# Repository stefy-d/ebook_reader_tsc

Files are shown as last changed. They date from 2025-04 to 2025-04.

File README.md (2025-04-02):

## **Manea Ștefania-Delia**
### **Grupa 335CC** 
<br><br>

# **Pașii de implementare**  
- Realizarea schematicului
- Plasarea componentelor pe PCB
- Trasarea circuitelor și optimizarea rutării semnalelor
- Încărcarea modelelor 3D pentru fiecare componentă
- Crearea bateriei și a display-ului
- Inserarea PCB-ului, a bateriei și a display-ului în carcasa 3D
<br><br> 

# **Diagramă bloc**
```` mermaid
graph TD;
    USB_C[USB C Connector & ESD Protection] -->|Power & Data| LDO[LDO Voltage Regulator];
    LDO -->|3.3V Power| ESP32[ESP32 C6];
    LDO -->|3.3V Power| SD[SD Card];
    LDO -->|3.3V Power| RTC[RTC Module DS3231SN];
    LDO -->|3.3V Power| Sensor[Environmental Sensor BME688];
    LDO -->|3.3V Power| Display[EPD Power];
    ESP32 -->|SPI| SD;
    ESP32 -->|I2C| RTC;
    ESP32 -->|I2C| Sensor;
    ESP32 -->|SPI| Display;
    ESP32 -->|GPIO| Button[Voltage Supervisor + Reset & Boot / IO Button];
    ESP32 -->|SPI| Flash[External NOR Flash 64MB];
    ESP32 -->|GPIO| ChargeLevel[Battery Charge Level];
    ESP32 -->|GPIO| Selector[Display Type Selector];
    ChargeController[Li-Po Battery Charging Controller] -->|Power| LDO;
    ChargeController -->|Battery Status| ChargeLevel;

`````
<br><br>

# **BOM (Bill Of Materials)**

| Componenta | X | Y | Rotatie | Valoare | Package | Link | 
|---|---|---|---|---|---|---|
| BOOT_BUTTON | 23.90  | 108.41 | 180.00 | BUTTON_CUSYOMV1 | MYBUTTON | https://industry.panasonic.com/global/en/products/control/switch/light-touch/number/evqpuj02k |
| C1 | 154.64 | 6.13 | 90.00 | 100nF | ESP32_WROVER_EAGLE-LTSPICE_C0402 | https://componentsearchengine.com/part-view/CC0402MRX5R5BB106/YAGEO |
| C10 | 67.34  | 107.83 | 270.00 | 100nF | ESP32_WROVER_EAGLE-LTSPICE_C0402 | https://componentsearchengine.com/part-view/CC0402MRX5R5BB106/YAGEO |
| C10_SUPERCAP | 93.09  | 55.34  | 90.00 | CPH3225A | CAPCP3225X100N  | https://www.snapeda.com/parts/CPH3225A/Seiko+Instruments/view-part/?ref=eda |
| C1_BAT | 107.73 | 50.25  | 0.00 | 4.7uF | ESP32_WROVER_EAGLE-LTSPICE_C0402 | https://componentsearchengine.com/part-view/CC0402MRX5R5BB106/YAGEO |
| C1_BAT1 | 109.19 | 37.99  | 0.00 | 4.7uF | ESP32_WROVER_EAGLE-LTSPICE_C0402 | https://componentsearchengine.com/part-view/CC0402MRX5R5BB106/YAGEO |
| C1_BAT2 | 104.58 | 40.47  | 90.00 | 4.7uF | ESP32_WROVER_EAGLE-LTSPICE_C0402 | https://componentsearchengine.com/part-view/CC0402MRX5R5BB106/YAGEO |
| C2 | 153.42 | 6.13 | 90.00 | 100nF | ESP32_WROVER_EAGLE-LTSPICE_C0402 | https://componentsearchengine.com/part-view/CC0402MRX5R5BB106/YAGEO |
| C2_BAT | 120.94 | 51.25  | 90.00 | 4.7uF | ESP32_WROVER_EAGLE-LTSPICE_C0402 | https://componentsearchengine.com/part-view/CC0402MRX5R5BB106/YAGEO |
| C3 | 118.89 | 41.40  | 90.00 | 100uF | RCL_CT3528 | https://eu.mouser.com/ProductDetail/KYOCERA-AVX/F910J107MBAAJ6?qs=PqoDHHvF649LraCA%2FjeGXg%3D%3D |
| C4 | 90.95  | 35.19  | 90.00 | 4.7uF/25V | ESP32_WROVER_EAGLE-LTSPICE_C0402 | https://componentsearchengine.com/part-view/CC0402MRX5R5BB106/YAGEO |
| C4_USB | 149.29 | 50.17  | 90.00 | 100nF | ESP32_WROVER_EAGLE-LTSPICE_C0402 | https://componentsearchengine.com/part-view/CC0402MRX5R5BB106/YAGEO |
| C5 | 52.21  | 107.71 | 270.00 | 1uF | ESP32_WROVER_EAGLE-LTSPICE_C0402 | https://componentsearchengine.com/part-view/CC0402MRX5R5BB106/YAGEO |
| C5_USB | 155.40 | 52.97  | 90.00 | 4.7uF | ESP32_WROVER_EAGLE-LTSPICE_C0402 | https://componentsearchengine.com/part-view/CC0402MRX5R5BB106/YAGEO |
| C6 | 27.30  | 107.83 | 270.00 | 100nF | ESP32_WROVER_EAGLE-LTSPICE_C0402 | https://componentsearchengine.com/part-view/CC0402MRX5R5BB106/YAGEO |
| C7 | 80.29  | 30.73  | 0.00 | 10uF | ESP32_WROVER_EAGLE-LTSPICE_C0402 | https://componentsearchengine.com/part-view/CC0402MRX5R5BB106/YAGEO |
| C8 | 84.28  | 52.43  | 180.00 | 100nF | ESP32_WROVER_EAGLE-LTSPICE_C0402 | https://componentsearchengine.com/part-view/CC0402MRX5R5BB106/YAGEO |
| C9 | 10.66  | 99.03  | 90.00 | 100nF | ESP32_WROVER_EAGLE-LTSPICE_C0402 | https://componentsearchengine.com/part-view/CC0402MRX5R5BB106/YAGEO |
| CHANGE_BUTTON  | 64.00  | 108.48 | 179.30 | BUTTON_CUSYOMV1 | MYBUTTON | https://industry.panasonic.com/global/en/products/control/switch/light-touch/number/evqpuj02k |
| CHG_LED | 111.34 | 50.15  | 90.00 | | ADAFRUIT_CHIP-LED0603 | https://www.snapeda.com/parts/KP-1608SURCK/Kingbright/view-part/?ref=search&t=LED%200603 |
| C_DELAY | 51.93  | 101.29 | 269.50 | 100nF | ESP32_WROVER_EAGLE-LTSPICE_C0402 | https://componentsearchengine.com/part-view/CC0402MRX5R5BB106/YAGEO |
| D1 | 152.58 | 50.47  | 0.00 | USBLC6-2SC6Y | SOT95P280X145-6N | https://www.snapeda.com/parts/USBLC6-2SC6Y/STMicroelectronics/view-part/?ref=eda |
| D10 | 44.62  | 38.77  | 90.00 | PGB1010603MR | DIOC1608X36N | https://www.snapeda.com/parts/PGB1010603MR/Littelfuse/view-part/?ref=eda |
| D11 | 42.60  | 38.67  | 90.00 | PGB1010603MR | DIOC1608X36N | https://www.snapeda.com/parts/PGB1010603MR/Littelfuse/view-part/?ref=eda |
| D12 | 38.38  | 38.87  | 90.00 | PGB1010603MR | DIOC1608X36N | https://www.snapeda.com/parts/PGB1010603MR/Littelfuse/view-part/?ref=eda |
| D2 | 122.09 | 41.08  | 90.00 | ESP32_WROVER_AVX---SD0805S020S1R0_AVX_SD0805S020S1R0_0_0AVX_SD0805S020S1R0_0_0 | ESP32_WROVER_AVX---SD0805S020S1R0_AVX_SD0805S020S1R0_0 | https://eu.mouser.com/ProductDetail/KYOCERA-AVX/SD0805S020S1R0?qs=jCA%252BPfw4LHbpkAoSnwrdjw%3D%3D |
| D3 | 87.16  | 35.47  | 180.00 | MBR0530 | SOD3716X135N | https://www.snapeda.com/parts/MBR0530/Onsemi/view-part/?ref=eda |
| D4 | 87.22  | 31.68  | 0.00 | MBR0530 | SOD3716X135N | https://www.snapeda.com/parts/MBR0530/Onsemi/view-part/?ref=eda |
| D5 | 80.26  | 40.58  | 180.00 | MBR0530 | SOD3716X135N | https://www.snapeda.com/parts/MBR0530/Onsemi/view-part/?ref=eda |
| D6 | 73.98  | 26.87  | 0.00 | PGB1010603MR | DIOC1608X36N | https://www.snapeda.com/parts/PGB1010603MR/Littelfuse/view-part/?ref=eda |
| D7 | 83.64  | 68.93  | 0.00 | ESP32_WROVER_AVX---SD0805S020S1R0_AVX_SD0805S020S1R0_0_0AVX_SD0805S020S1R0_0_0 | ESP32_WROVER_AVX---SD0805S020S1R0_AVX_SD0805S020S1R0_0 | https://eu.mouser.com/ProductDetail/KYOCERA-AVX/SD0805S020S1R0?qs=jCA%252BPfw4LHbpkAoSnwrdjw%3D%3D |
| D8 | 14.96  | 98.57  | 0.00 | PGB1010603MR | DIOC1608X36N | https://www.snapeda.com/parts/PGB1010603MR/Littelfuse/view-part/?ref=eda
| D9 | 33.14  | 47.17  | 270.00 | PGB1010603MR | DIOC1608X36N | https://www.snapeda.com/parts/PGB1010603MR/Littelfuse/view-part/?ref=eda |
| EPD_C1 | 88.71  | 21.47  | 90.00 | 1uF/50V | ESP32_WROVER_EAGLE-LTSPICE_C0402 | https://componentsearchengine.com/part-view/CC0402MRX5R5BB106/YAGEO |
| EPD_C10 | 76.31  | 21.47  | 90.00 | 1uF/50V | ESP32_WROVER_EAGLE-LTSPICE_C0402 | https://componentsearchengine.com/part-view/CC0402MRX5R5BB106/YAGEO |
| EPD_C11 | 72.05  | 18.89  | 90.00 | 1uF/50V | ESP32_WROVER_EAGLE-LTSPICE_C0402 | https://componentsearchengine.com/part-view/CC0402MRX5R5BB106/YAGEO |
| EPD_C12 | 70.61  | 18.79  | 90.00 | 1uF/50V | ESP32_WROVER_EAGLE-LTSPICE_C0402 | https://componentsearchengine.com/part-view/CC0402MRX5R5BB106/YAGEO |
| EPD_C2 | 87.32  | 21.47  | 90.00 | 1uF/50V | ESP32_WROVER_EAGLE-LTSPICE_C0402 | https://componentsearchengine.com/part-view/CC0402MRX5R5BB106/YAGEO |
| EPD_C5 | 85.68  | 21.45  | 90.00 | 1uF/50V | ESP32_WROVER_EAGLE-LTSPICE_C0402 | https://componentsearchengine.com/part-view/CC0402MRX5R5BB106/YAGEO |
| EPD_C6 | 81.95  | 21.49  | 270.00 | 1uF/50V | ESP32_WROVER_EAGLE-LTSPICE_C0402 | https://componentsearchengine.com/part-view/CC0402MRX5R5BB106/YAGEO |
| EPD_C7 | 80.55  | 21.50  | 90.00 | 1uF/50V | ESP32_WROVER_EAGLE-LTSPICE_C0402 | https://componentsearchengine.com/part-view/CC0402MRX5R5BB106/YAGEO |
| EPD_C8 | 79.15  | 21.51  | 90.00 | 1uF/50V | ESP32_WROVER_EAGLE-LTSPICE_C0402 | https://componentsearchengine.com/part-view/CC0402MRX5R5BB106/YAGEO |
| EPD_C9 | 77.75  | 21.52  | 90.00 | 1uF/50V | ESP32_WROVER_EAGLE-LTSPICE_C0402 | https://componentsearchengine.com/part-view/CC0402MRX5R5BB106/YAGEO |
| IC1 | 48.65  | 101.27 | 0.00 | BD5229G-TR | SOT95P280X125-5N | https://componentsearchengine.com/part-view/BD5229G-TR/ROHM%20Semiconductor |
| IC4 | 113.73 | 40.29  | 0.00 | XC6220A331MR-G | SOT95P280X120-5N | https://componentsearchengine.com/part-view/XC6220A331MR-G/Torex |
| J1 | 83.10  | 14.17  | 0.00 | FH34SRJ-24S-0.5SH_99_ | FH34SRJ24S05SH99 | https://componentsearchengine.com/part-view/FH34SRJ-24S-0.5SH(99)/Hirose |
| J2 | 165.53 | 54.30  | 90.00 | SAMACSYS_PARTS_USB4110-GF-A | SAMACSYS_PARTS_USB4110GFA | https://componentsearchengine.com/part-view/USB4110-GF-A/GCT%20(GLOBAL%20CONNECTOR%20TECHNOLOGY) |
| J3 | 166.35 | 19.30  | 90.00 | QWIIC_RIGHT_ANGLE | JST04_1MM_RA | https://eu.mouser.com/ProductDetail/Adafruit/4208?qs=PzGy0jfpSMtbScLbr0L5dw%3D%3D |
| J4 | 9.09 | 88.88  | 270.00 | 112A-TAAR-R03_ATTEND | 112ATAARR03ATTEND | https://store.comet.srl.ro/Catalogue/Product/43497/ |
| L1 | 80.35  | 35.77  | 270.00 | 68uH | IND_4828-WE-TPC_WRE | https://eu.mouser.com/ProductDetail/Wurth-Elektronik/744043680?qs=PGXP4M47uW6VkZq%252BkzjrHA%3D%3D |
| MCP73831  | 116.79 | 49.69  | 90.00 | ESP32_WROVER_SPARKFUN-IC-POWER_MCP73831 | ESP32_WROVER_SPARKFUN-IC-POWER_SOT23-5 | https://eu.mouser.com/ProductDetail/Microchip-Technology/MCP73831T-2ACI-OT?qs=yUQqVecv4qvbBQBGbHx0Mw%3D%3D |
| PFMF.050.1| 151.74 | 43.60  | 0.00 | ESP32C6_VARISTORCN1812 | ESP32C6_VARISTOR_CT/CN1812 | https://www.mouser.co.uk/ProductDetail/EPCOS-TDK/B72520T0350K062?qs=dEfas%2FXlABIszF52uu7vrg%3D%3D |
| Q1 | 123.56 | 47.31  | 0.00 | 20V/4.2A/52mΩ/1.4W | ESP32_WROVER_SPARKFUN-DISCRETESEMI_SOT23-3 | https://componentsearchengine.com/part-view/DMG2305UX-7/Diodes%20Incorporated |
| Q2 | 76.03  | 31.36  | 270.00 | 20V/4.2A/52mΩ/1.4W | ESP32_WROVER_SPARKFUN-DISCRETESEMI_SOT23-3 | https://componentsearchengine.com/part-view/DMG2305UX-7/Diodes%20Incorporated |
| Q3 | 67.19  | 15.28  | 90.00 | SI1308EDL-T1-GE3 | SOT65P210X110-3N | https://www.snapeda.com/parts/SI1308EDL-T1-GE3/Vishay+Siliconix/view-part/?ref=eda |
| R1 | 19.35  | 42.13  | 270.00 | 10K | ESP32_WROVER_EAGLE-LTSPICE_R0402 | https://componentsearchengine.com/part-view/R0402%201%25%20100%20K%20(RC0402FR-07100KL)/YAGEO |
| R10 | 12.23  | 99.03  | 90.00 | 10K | ESP32_WROVER_EAGLE-LTSPICE_R0402 | https://componentsearchengine.com/part-view/R0402%201%25%20100%20K%20(RC0402FR-07100KL)/YAGEO |
| R1_BAT | 111.55 | 48.75  | 0.00 | 200 | ESP32_WROVER_EAGLE-LTSPICE_R0402 |
| R1_PINH | 156.12 | 6.27 | 90.00 | 10K | ESP32_WROVER_EAGLE-LTSPICE_R0402 | https://componentsearchengine.com/part-view/R0402%201%25%20100%20K%20(RC0402FR-07100KL)/YAGEO |
| R1_PINH1  | 83.56  | 66.94  | 0.00 | 10K | ESP32_WROVER_EAGLE-LTSPICE_R0402 | https://componentsearchengine.com/part-view/R0402%201%25%20100%20K%20(RC0402FR-07100KL)/YAGEO |
| R1_PWRUSB | 106.25 | 40.54  | 90.00 | 100k | ESP32_WROVER_EAGLE-LTSPICE_R0402 | https://componentsearchengine.com/part-view/R0402%201%25%20100%20K%20(RC0402FR-07100KL)/YAGEO |
| R2 | 65.73  | 11.51  | 0.00 | 2.2 | ESP32_WROVER_EAGLE-LTSPICE_R0402 | https://componentsearchengine.com/part-view/R0402%201%25%20100%20K%20(RC0402FR-07100KL)/YAGEO |
| R2-PINH | 157.48 | 6.27 | 90.00 | 10K | ESP32_WROVER_EAGLE-LTSPICE_R0402 | https://componentsearchengine.com/part-view/R0402%201%25%20100%20K%20(RC0402FR-07100KL)/YAGEO |
| R2-USB | 152.58 | 46.33  | 0.00 | 5k1 | ESP32_WROVER_EAGLE-LTSPICE_R0402 | https://componentsearchengine.com/part-view/R0402%201%25%20100%20K%20(RC0402FR-07100KL)/YAGEO |
| R2-USB1 | 152.56 | 47.77  | 0.00 | 5k1 | ESP32_WROVER_EAGLE-LTSPICE_R0402 | https://componentsearchengine.com/part-view/R0402%201%25%20100%20K%20(RC0402FR-07100KL)/YAGEO |
| R2_BAT | 115.66 | 46.05  | 90.00 | 2K | ESP32_WROVER_EAGLE-LTSPICE_R0402 | https://componentsearchengine.com/part-view/R0402%201%25%20100%20K%20(RC0402FR-07100KL)/YAGEO |
| R2_PINH1  | 89.11  | 63.79  | 90.00 | 10K | ESP32_WROVER_EAGLE-LTSPICE_R0402 | https://componentsearchengine.com/part-view/R0402%201%25%20100%20K%20(RC0402FR-07100KL)/YAGEO |
| R3 | 68.71  | 9.53 | 90.00 | 0.47 | ESP32_WROVER_EAGLE-LTSPICE_R0402 | https://componentsearchengine.com/part-view/R0402%201%25%20100%20K%20(RC0402FR-07100KL)/YAGEO |
| R4 | 70.49  | 13.91  | 0.00 | 10K | ESP32_WROVER_EAGLE-LTSPICE_R0402 | https://componentsearchengine.com/part-view/R0402%201%25%20100%20K%20(RC0402FR-07100KL)/YAGEO |
| R5 | 31.21  | 47.21  | 270.00 | 10K | ESP32_WROVER_EAGLE-LTSPICE_R0402 | https://componentsearchengine.com/part-view/R0402%201%25%20100%20K%20(RC0402FR-07100KL)/YAGEO |
| R6 | 44.53  | 33.41  | 92.20 | 10K | ESP32_WROVER_EAGLE-LTSPICE_R0402 | https://componentsearchengine.com/part-view/R0402%201%25%20100%20K%20(RC0402FR-07100KL)/YAGEO |
| R7 | 42.45  | 33.61  | 270.00 | 10K | ESP32_WROVER_EAGLE-LTSPICE_R0402 | https://componentsearchengine.com/part-view/R0402%201%25%20100%20K%20(RC0402FR-07100KL)/YAGEO |
| R8 | 38.57  | 33.41  | 90.00 | 10K | ESP32_WROVER_EAGLE-LTSPICE_R0402 | https://componentsearchengine.com/part-view/R0402%201%25%20100%20K%20(RC0402FR-07100KL)/YAGEO |
| R9 | 70.89  | 31.31  | 90.00 | 10K | ESP32_WROVER_EAGLE-LTSPICE_R0402 | https://componentsearchengine.com/part-view/R0402%201%25%20100%20K%20(RC0402FR-07100KL)/YAGEO |
| RESET_BUTTON | 48.90 | 108.49 | 180.40 | BUTTON_CUSYOMV1  | MYBUTTON | https://industry.panasonic.com/global/en/products/control/switch/light-touch/number/evqpuj02k |
| R_BOOT | 20.27  | 107.67  | 270.00 | 10K | ESP32_WROVER_EAGLE-LTSPICE_R0402 | https://componentsearchengine.com/part-view/R0402%201%25%20100%20K%20(RC0402FR-07100KL)/YAGEO |
| R_CAPACITOR | 88.95 | 55.04  | 270.00 | 15 | ESP32_WROVER_EAGLE-LTSPICE_R0402 | https://componentsearchengine.com/part-view/R0402%201%25%20100%20K%20(RC0402FR-07100KL)/YAGEO |
| R_CHANGE  | 60.62  | 107.78  | 90.00 | 10K | ESP32_WROVER_EAGLE-LTSPICE_R0402 | https://componentsearchengine.com/part-view/R0402%201%25%20100%20K%20(RC0402FR-07100KL)/YAGEO |
| R_CL1 | 72.96  | 31.23  | 90.00 | 10K | ESP32_WROVER_EAGLE-LTSPICE_R0402 | https://componentsearchengine.com/part-view/R0402%201%25%20100%20K%20(RC0402FR-07100KL)/YAGEO |
| R_RESET | 45.19  | 107.69  | 269.80 | 10K | ESP32_WROVER_EAGLE-LTSPICE_R0402 | https://componentsearchengine.com/part-view/R0402%201%25%20100%20K%20(RC0402FR-07100KL)/YAGEO |
| SENSOR2 | 154.46 | 10.42  | 90.00 | ESP32_WROVER_BME680_BME680 | ESP32_WROVER_BME680_PSON80P300X300X100-8N | https://www.snapeda.com/parts/BME680/Bosch/view-part/?welcome=home |
| SJ1 | 65.86  | 9.29 | 0.00 | | SJ | https://grabcad.com/library/solder-jumpers-1 |
| TP1 | 10.51  | 67.29  | 0.00 | TPTP20R | TP20R | CUSTOM
| TP10 | 104.28 | 15.51  | 0.00 | TPTP20R | TP20R | CUSTOM
| TP11 | 100.19 | 19.39  | 0.00 | TPTP20R | TP20R | CUSTOM
| TP12 | 99.83  | 15.81  | 0.00 | TPTP20R | TP20R | CUSTOM
| TP13 | 94.86  | 15.83  | 0.00 | TPTP20R | TP20R | CUSTOM
| TP14 | 135.63 | 50.31  | 0.00 | TPTP20R | TP20R | CUSTOM
| TP15 | 78.68  | 70.51  | 0.00 | TPTP20R | TP20R | CUSTOM
| TP16 | 9.43 | 41.31  | 0.00 | TPTP20R | TP20R | CUSTOM
| TP17 | 95.62  | 19.47  | 0.00 | TPTP20R | TP20R | CUSTOM
| TP2 | 14.23  | 67.49  | 0.00 | TPTP20R | TP20R | CUSTOM
| TP3 | 131.25 | 50.56  | 0.00 | TPTP20R | TP20R | CUSTOM
| TP4 | 131.37 | 54.49  | 0.00 | TPTP20R | TP20R | CUSTOM
| TP5 | 135.89 | 54.39  | 0.00 | TPTP20R | TP20R | CUSTOM
| TP6 | 16.11  | 77.59  | 0.00 | TPTP20R | TP20R | CUSTOM
| TP7 | 11.03  | 77.59  | 0.00 | TPTP20R | TP20R | CUSTOM
| TP8 | 5.95 | 77.59  | 0.00 | TPTP20R | TP20R | CUSTOM
| TP9 | 104.67 | 19.19  | 0.00 | TPTP20R | TP20R | CUSTOM
| U1 | 36.89  | 54.16  | 0.00 | W25Q512JVEIQ | SON127P600X800X80-9N | https://www.snapeda.com/parts/W25Q512JVEIQ/Winbond+Electronics/view-part/?ref=eda |
| U2 | 16.20  | 54.00  | 90.00 | ESP32-C6-WROOM-1-N8 | XCVR_ESP32-C6-WROOM-1-N8 | https://www.snapeda.com/parts/ESP32-C6-WROOM-1-N8/Espressif+Systems/view-part/?ref=eda |
| U3 | 79.90  | 59.90  | 270.00 | DS3231SN# | SOIC127P1032X265-16N | https://www.snapeda.com/parts/DS3231SN%23/Analog+Devices/view-part/?ref=eda |
| U4 | 126.58 | 50.72  | 0.00 | MAX17048G+T10 | SON50P200X200X80-9N | https://www.snapeda.com/parts/MAX17048G+T10/Analog+Devices/view-part/?ref=eda |

<br><br>

# **Pini ESP32-C6**

ESP32-C6 are mai mulți pini utilizați pentru conectarea componentelor din schema bloc. Mai jos este o descriere detaliată a pinilor folosiți și justificarea utilizării lor:

### **1. SD Card (SPI)**
   - **Pini utilizați**:
     - **IO6 (CLK/SCK)** - Semnal de ceas SPI
     - **IO7 (MOSI)** - Linie de date pentru transmitere
     - **IO2 (MISO)** - Linie de date pentru recepție
     - **IO10 (CS)** - Chip Select pentru activarea cardului SD
   - **Motiv**: Protocolul SPI este ideal pentru cardurile SD, deoarece permite viteze mari de transfer cu un număr redus de pini.

### **2. RTC Module DS3231SN (I2C)**
   - **Pini utilizați**:
     - **IO8 (SCL)** - Linie de ceas I2C
     - **IO9 (SDA)** - Linie de date I2C
   - **Motiv**: DS3231SN folosește protocolul I2C pentru comunicație, ceea ce permite partajarea magistralei cu alți senzori.

### **3. Environmental Sensor BME688 (I2C)**
   - **Pini utilizați**:
     - **IO8 (SCL)** - Linie de ceas I2C (partajat cu RTC)
     - **IO9 (SDA)** - Linie de date I2C (partajat cu RTC)
   - **Motiv**: Folosind I2C, senzorul poate comunica eficient cu ESP32 fără a ocupa pini suplimentari.

### **4. EPD Power (SPI)**
   - **Pini utilizați**:
     - **IO6 (CLK/SCK)** - Semnal de ceas SPI
     - **IO7 (MOSI)** - Linie de date pentru transmitere
     - **IO2 (MISO)** - Linie de date pentru recepție
     - **IO5 (CS)** - Chip Select pentru activarea display-ului
   - **Motiv**: Ecranele E-Paper folosesc adesea SPI datorită vitezei mari de transmitere și latenței reduse.

### **5. Voltage Supervisor + Reset & Boot / IO Button (GPIO)**
   - **Pini utilizați**:
     - **IO0** - Buton BOOT
     - **IO3** - Buton Reset
   - **Motiv**: ESP32 folosește aceste pini pentru a intra în mod de programare și resetare rapidă.

### **6. External NOR Flash 64MB (SPI)**
   - **Pini utilizați**:
     - **IO6 (CLK/SCK)** - Semnal de ceas SPI
     - **IO7 (MOSI)** - Linie de date pentru transmitere
     - **IO2 (MISO)** - Linie de date pentru recepție
     - **IO4 (CS)** - Chip Select pentru activarea memoriei Flash
   - **Motiv**: ESP32 poate extinde memoria utilizând SPI pentru a accesa rapid datele stocate.

### **7. Battery Charge Level (GPIO)**
   - **Pini utilizați**:
     - **IO12 (ADC1_CH3)** - Intrare analogică pentru măsurarea tensiunii bateriei
   - **Motiv**: ESP32 dispune de convertoare ADC care permit măsurarea nivelului de încărcare al bateriei.

### **8. Display Type Selector (GPIO)**
   - **Pini utilizați**:
     - **IO14** - Selector de tip ecran (ex. alb-negru vs. color)
   - **Motiv**: Un pin GPIO poate fi folosit pentru a configura sau selecta diferite moduri de operare ale ecranului.

<br><br>

# **Descriere hardware**  

## **1. Microcontrolerul principal – ESP32-C6**  

ESP32-C6 gestionează toate componentele conectate prin diverse protocoale de comunicație, asigurând interfațarea eficientă cu acestea.  

---

## **2. Module și senzori conectați la ESP32-C6: ca mai sus**  

### **2.1. Stocare – Card SD**  
- **Interfață de comunicare**: SPI   

---

### **2.2. Modul RTC DS3231SN**  
- **Interfață de comunicare**: I2C   

---

### **2.3. Senzor BME688** 
- **Interfață de comunicare**: I2C  

---

### **2.4. Ecran E-Paper (SPI)**  
- **Interfață de comunicare**: SPI 

---

### **2.5. Memorie externă NOR Flash 64MB**  
- **Interfață de comunicare**: SPI   

---

### **2.6. Butoane pentru control**   
- **Interfață de comunicare**: GPIO    

---

### **2.7. Monitorizare baterie**  
- **Interfață de comunicare**: GPIO / ADC  

---

### **2.8. Selector de tip ecran**   
- **Interfață de comunicare**: GPIO  

---

### **3. Alimentare și managementul energiei**  

ESP32-C6 și toate componentele funcționează la **3.3V**, alimentarea fiind gestionată de:  

1. **Regulator de tensiune LDO**   

2. **Controler de încărcare baterie Li-Po**  

---

### **4. Rezumat**  

| **Componentă** | **Interfață** | **Pini ESP32-C6** |
|---|---|---|
| **Card SD** | SPI | IO6, IO7, IO2, IO10 |
| **RTC DS3231SN** | I2C | IO8, IO9 |
| **Senzor BME688** | I2C | IO8, IO9 |
| **Display E-Paper** | SPI | IO6, IO7, IO2, IO5 |
| **Memorie NOR Flash 64MB** | SPI | IO6, IO7, IO2, IO4 |
| **Butoane de control** | GPIO | IO0, IO3 |
| **Monitorizare baterie** | ADC/GPIO | IO12 |
| **Selector de tip ecran** | GPIO | IO14 |

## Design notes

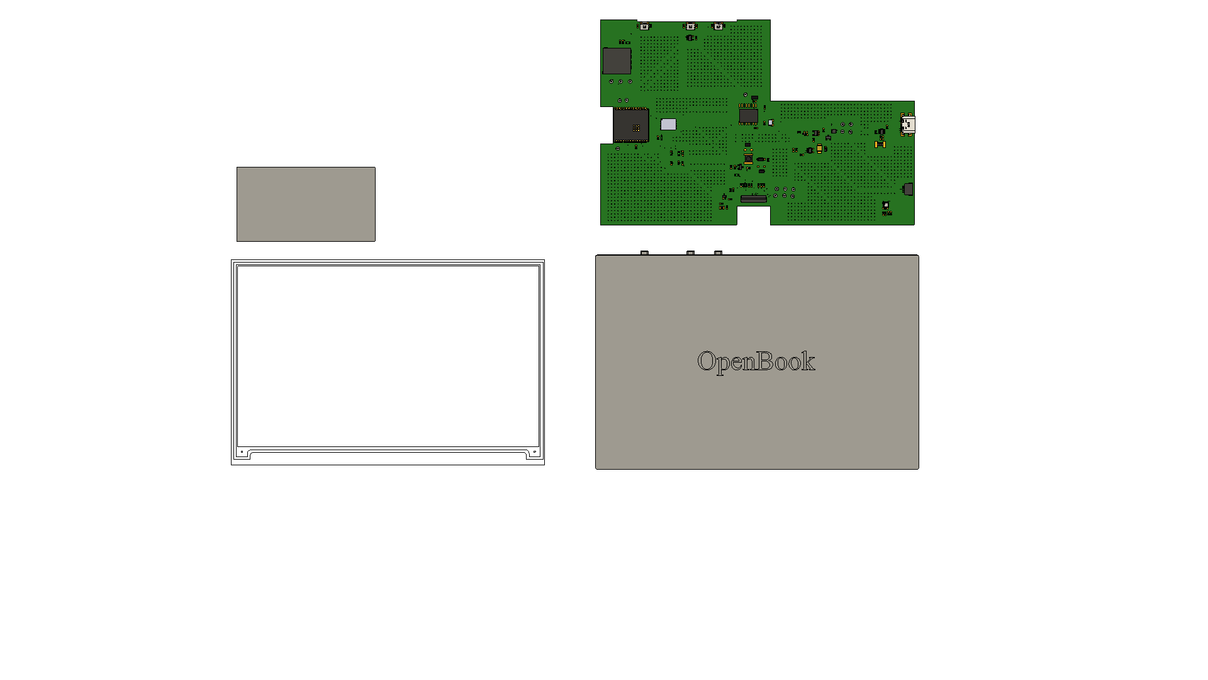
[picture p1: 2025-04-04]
Images/exploded.png

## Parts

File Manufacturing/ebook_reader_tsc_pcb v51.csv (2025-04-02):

Qty | Value | Device | Package | Parts | Description | ARROW_PART_NUMBER | ARROW_PRICE-STOCK | AVAILABILITY | CENTROID_NOT_SPECIFIED | CHECK_PRICES | COPYRIGHT | DATASHEET | DESCRIPTION | DIGIKEY_DESCRIPTION | DIGIKEY_PART_NUMBER | HEIGHT | LEAD_FREE | MANUFACTURER_NAME | MANUFACTURER_PART_NUMBER | MF | MFR_NAME | MOUSER_PART_NUMBER | MOUSER_PRICE-STOCK | MOUSER_TESTING_PART_NUMBER | MOUSER_TESTING_PRICE-STOCK | MP | MPN | PACKAGE | POPULARITY | PREFIX | PRICE | PROD_ID | PURCHASE-URL | ROHS | SNAPEDA_LINK | SPICEMODEL | SPICEPREFIX | TEMPERATURE_RANGE_HIGH | TEMPERATURE_RANGE_LOW | TP_SIGNAL_NAME | VALUE
1 |  | ADAFRUIT_LEDCHIP-LED0603 | ADAFRUIT_CHIP-LED0603 | CHG_LED | LED
1 |  | SJ | SJ | SJ1 | SMD solder JUMPER |  |  |  |  |  |  |  |  |  |  |  |  |  |  |  |  |  |  |  |  |  |  |  | 3
1 | 0.47 | ESP32_WROVER_EAGLE-LTSPICE_RR0402 | ESP32_WROVER_EAGLE-LTSPICE_R0402 | R3 | RESISTOR, European symbol |  |  |  |  |  |  |  |  |  |  |  |  |  |  |  |  |  |  |  |  |  |  |  |  |  |  |  |  |  |  | NONE | R
1 | 100k | ESP32_WROVER_EAGLE-LTSPICE_RR0402 | ESP32_WROVER_EAGLE-LTSPICE_R0402 | R1_PWRUSB | RESISTOR, European symbol |  |  |  |  |  |  |  |  |  |  |  |  |  |  |  |  |  |  |  |  |  |  |  |  |  |  |  |  |  |  | NONE | R
8 | 100nF | ESP32_WROVER_EAGLE-LTSPICE_CC0402 | ESP32_WROVER_EAGLE-LTSPICE_C0402 | C1, C2, C4_USB, C6, C8, C9, C10, C_DELAY | CAPACITOR, European symbol |  |  |  |  |  |  |  |  |  |  |  |  |  |  |  |  |  |  |  |  |  |  |  |  |  |  |  |  |  |  | NONE | C
1 | 100uF | RCL_CPOL-EUCT3528 | RCL_CT3528 | C3 | POLARIZED CAPACITOR, European symbol |  |  |  |  |  |  |  |  |  |  |  |  |  |  |  |  |  |  |  |  |  |  |  | 0 |  |  |  |  |  |  |  | C
16 | 10K | ESP32_WROVER_EAGLE-LTSPICE_RR0402 | ESP32_WROVER_EAGLE-LTSPICE_R0402 | R1, R1_PINH, R1_PINH1, R2-PINH, R2_PINH1, R4, R5, R6, R7, R8, R9, R10, R_BOOT, R_CHANGE, R_CL1, R_RESET | RESISTOR, European symbol |  |  |  |  |  |  |  |  |  |  |  |  |  |  |  |  |  |  |  |  |  |  |  |  |  |  |  |  |  |  | NONE | R
1 | 10uF | ESP32_WROVER_EAGLE-LTSPICE_CC0402 | ESP32_WROVER_EAGLE-LTSPICE_C0402 | C7 | CAPACITOR, European symbol |  |  |  |  |  |  |  |  |  |  |  |  |  |  |  |  |  |  |  |  |  |  |  |  |  |  |  |  |  |  | NONE | C
1 | 112A-TAAR-R03_ATTEND | 112A-TAAR-R03_ATTEND | 112ATAARR03ATTEND | J4 | Micro SD Card Socket, Push-Push Type, Top Mount, SMT, H=1.83mm, 10u |  |  |  |  |  |  |  | Micro SD Card Socket | Push-Push Type | Top Mount | SMT | H=1.83mm | 10u |  |  | 1.9mm |  | ATTEND | 112A-TAAR-R03 ATTEND
1 | 15 | ESP32_WROVER_EAGLE-LTSPICE_RR0402 | ESP32_WROVER_EAGLE-LTSPICE_R0402 | R_CAPACITOR | RESISTOR, European symbol |  |  |  |  |  |  |  |  |  |  |  |  |  |  |  |  |  |  |  |  |  |  |  |  |  |  |  |  |  |  | NONE | R
1 | 1uF | ESP32_WROVER_EAGLE-LTSPICE_CC0402 | ESP32_WROVER_EAGLE-LTSPICE_C0402 | C5 | CAPACITOR, European symbol |  |  |  |  |  |  |  |  |  |  |  |  |  |  |  |  |  |  |  |  |  |  |  |  |  |  |  |  |  |  | NONE | C
10 | 1uF/50V | ESP32_WROVER_EAGLE-LTSPICE_CC0402 | ESP32_WROVER_EAGLE-LTSPICE_C0402 | EPD_C1, EPD_C2, EPD_C5, EPD_C6, EPD_C7, EPD_C8, EPD_C9, EPD_C10, EPD_C11, EPD_C12 | CAPACITOR, European symbol |  |  |  |  |  |  |  |  |  |  |  |  |  |  |  |  |  |  |  |  |  |  |  |  |  |  |  |  |  |  | NONE | C
1 | 2.2 | ESP32_WROVER_EAGLE-LTSPICE_RR0402 | ESP32_WROVER_EAGLE-LTSPICE_R0402 | R2 | RESISTOR, European symbol |  |  |  |  |  |  |  |  |  |  |  |  |  |  |  |  |  |  |  |  |  |  |  |  |  |  |  |  |  |  | NONE | R
1 | 200 | ESP32_WROVER_EAGLE-LTSPICE_RR0402 | ESP32_WROVER_EAGLE-LTSPICE_R0402 | R1_BAT | RESISTOR, European symbol |  |  |  |  |  |  |  |  |  |  |  |  |  |  |  |  |  |  |  |  |  |  |  |  |  |  |  |  |  |  | NONE | R
2 | 20V/4.2A/52m?/1.4W | ESP32_WROVER_SPARKFUN-DISCRETESEMI_MOSFET_PCH-DMG2305UX-7 | ESP32_WROVER_SPARKFUN-DISCRETESEMI_SOT23-3 | Q1, Q2 | P-channel MOSFETs |  |  |  |  |  |  |  |  |  |  |  |  |  |  |  |  |  |  |  |  |  |  |  |  |  |  | TRAN-14388 |  |  |  |  |  |  |  |  | 20V/4.2A/52m?/1.4W
1 | 2K | ESP32_WROVER_EAGLE-LTSPICE_RR0402 | ESP32_WROVER_EAGLE-LTSPICE_R0402 | R2_BAT | RESISTOR, European symbol |  |  |  |  |  |  |  |  |  |  |  |  |  |  |  |  |  |  |  |  |  |  |  |  |  |  |  |  |  |  | NONE | R
5 | 4.7uF | ESP32_WROVER_EAGLE-LTSPICE_CC0402 | ESP32_WROVER_EAGLE-LTSPICE_C0402 | C1_BAT, C1_BAT1, C1_BAT2, C2_BAT, C5_USB | CAPACITOR, European symbol |  |  |  |  |  |  |  |  |  |  |  |  |  |  |  |  |  |  |  |  |  |  |  |  |  |  |  |  |  |  | NONE | C
1 | 4.7uF/25V | ESP32_WROVER_EAGLE-LTSPICE_CC0402 | ESP32_WROVER_EAGLE-LTSPICE_C0402 | C4 | CAPACITOR, European symbol |  |  |  |  |  |  |  |  |  |  |  |  |  |  |  |  |  |  |  |  |  |  |  |  |  |  |  |  |  |  | NONE | C
2 | 5k1 | ESP32_WROVER_EAGLE-LTSPICE_RR0402 | ESP32_WROVER_EAGLE-LTSPICE_R0402 | R2-USB, R2-USB1 | RESISTOR, European symbol |  |  |  |  |  |  |  |  |  |  |  |  |  |  |  |  |  |  |  |  |  |  |  |  |  |  |  |  |  |  | NONE | R
1 | 68uH | 744043680IND_4828-WE-TPC_WRE | IND_4828-WE-TPC_WRE | L1 |  |  |  |  |  |  | Copyright (C) 2024 Ultra Librarian. All rights reserved. |  |  |  |  |  |  |  | 744043680 |  | Wurth Electronics
1 | BD5229G-TR | BD5229G-TR | SOT95P280X125-5N | IC1 | Voltage Detector with Adjustable Delay Time: CMOS processes are utilized to develop high precision, low current consumption CMOS reset ICs that allow arbitrary setting of the delay time. The extensive lineup includes both Nch Open Drain and CMOS output types in a wide range of detection voltages (from 2.3V to 6.0V, in 0.1V steps), enabling selection of the ideal solution based on customer requirements. In addition, the entire series is of course both lead-free and RoHS-compliant. |  |  |  |  |  |  |  | Voltage Detector with Adjustable Delay Time: CMOS processes are utilized to develop high precision | low current consumption CMOS reset ICs that allow arbitrary setting of the delay time. The extensive lineup includes both Nch Open Drain and CMOS output types in a wide range of detection voltages (from 2.3V to 6.0V | in 0.1V steps) | enabling selection of the ideal solution based on customer requirements. In addition | the entire series is of course both lead-free and RoHS-compliant. |  |  | 1.25mm |  | ROHM Semiconductor | BD5229G-TR |  |  | 755-BD5229G-TR | https://www.mouser.co.uk/ProductDetail/ROHM-Semiconductor/BD5229G-TR?qs=4kLU8WoGk0vvnhrrYwdszw%3D%3D
3 | BUTTON_CUSYOMV1 | BUTTON_CUSYOMV1 | MYBUTTON | BOOT_BUTTON, CHANGE_BUTTON, RESET_BUTTON
1 | CPH3225A | CPH3225A | CAPCP3225X100N | C10_SUPERCAP | Cap 0.011F 3.3V 1210 Flat Check availability |  |  | Not in stock |  | https://www.snapeda.com/parts/CPH3225A/Seiko+Instruments/view-part/?ref=eda |  |  | 11 mF (EDLC) Supercapacitor 3.3 V 1210 (3225 Metric) - - |  |  |  |  |  |  | Seiko Instruments |  |  |  |  |  | CPH3225A |  | 1210 Seiko |  |  | None |  | https://www.snapeda.com/api/url_track_click_mouser/?unipart_id=562593&manufacturer=Seiko Instruments&part_name=CPH3225A&search_term=None |  | https://www.snapeda.com/parts/CPH3225A/Seiko+Instruments/view-part/?ref=snap
1 | DS3231SN# | DS3231SN# | SOIC127P1032X265-16N | U3 | Real Time Clock Serial 16-Pin SOIC W T/R Check availability |  |  | In Stock |  | https://www.snapeda.com/parts/DS3231SN%23/Analog+Devices/view-part/?ref=eda |  |  | Extremely Accurate I2C-Integrated RTC/TCXO/Crystal |  |  |  |  |  |  | Analog Devices |  |  |  |  |  | DS3231SN# |  | SOIC-16 Maxim |  |  | None |  | https://www.snapeda.com/api/url_track_click_mouser/?unipart_id=99048&manufacturer=Analog Devices&part_name=DS3231SN#&search_term=None |  | https://www.snapeda.com/parts/DS3231SN%23/Analog+Devices/view-part/?ref=snap
1 | ESP32-C6-WROOM-1-N8 | ESP32-C6-WROOM-1-N8 | XCVR_ESP32-C6-WROOM-1-N8 | U2 | Check availability |  |  | In Stock |  | https://www.snapeda.com/parts/ESP32-C6-WROOM-1-N8/Espressif+Systems/view-part/?ref=eda |  |  | Multiprotocol Modules ESP32-C6 module | Wi-Fi 6 in 2.4 GHz band | Bluetooth 5 | Zigbee 3.0 and Thread. ESP34-WROOM Compatible - ENGINEERING SAMPLE |  |  |  |  |  |  | Espressif Systems |  |  |  |  |  | ESP32-C6-WROOM-1-N8 |  | None |  |  | None |  |  |  | https://www.snapeda.com/parts/ESP32-C6-WROOM-1-N8/Espressif+Systems/view-part/?ref=snap
1 | ESP32C6_VARISTORCN1812 | ESP32C6_VARISTORCN1812 | ESP32C6_VARISTOR_CT/CN1812 | PFMF.050.1 | VARISTOR |  |  |  |  |  |  |  |  |  |  |  |  |  |  |  |  |  |  |  |  |  |  |  | 0
2 | ESP32_WROVER_AVX---SD0805S020S1R0_AVX_SD0805S020S1R0_0_0AVX_SD0805S020S1R0_0_0 | ESP32_WROVER_AVX---SD0805S020S1R0_AVX_SD0805S020S1R0_0_0AVX_SD0805S020S1R0_0_0 | ESP32_WROVER_AVX---SD0805S020S1R0_AVX_SD0805S020S1R0_0 | D2, D7 | Schottky Barrier Rectifier Diode |  |  |  | No |  |  | http://datasheets.avx.com/schottky.pdf |  | DIODE SCHOTTKY 20V 1A 0805 | 478-7800-1-ND |  | yes |  |  | AVX |  | 581-SD0805S020S1R0 |  |  |  |  |  | 0805 (2012 metric) |  | D |  |  |  | yes |  |  |  | +125°C | -55°C
1 | ESP32_WROVER_BME680_BME680 | ESP32_WROVER_BME680_BME680 | ESP32_WROVER_BME680_PSON80P300X300X100-8N | SENSOR2 | Integrated Environmental Unit |  |  | Unavailable |  |  |  |  | Integrated Environmental Unit |  |  |  |  |  |  | Bosch Sensortec |  |  |  |  |  | BME680 |  | LGA-8 Bosch Tools |  |  | None
1 | ESP32_WROVER_SPARKFUN-IC-POWER_MCP73831 | ESP32_WROVER_SPARKFUN-IC-POWER_MCP73831 | ESP32_WROVER_SPARKFUN-IC-POWER_SOT23-5 | MCP73831 | MCP73831T Li-Ion, Li-Pol Controller |  |  |  |  |  |  |  |  |  |  |  |  |  |  |  |  |  |  |  |  |  |  |  |  |  |  | IC-09995
1 | FH34SRJ-24S-0.5SH_99_ | FH34SRJ-24S-0.5SH_99_ | FH34SRJ24S05SH99 | J1 | (0.50mm) Surface Mount, Right Angle |  |  |  |  |  |  |  | 24 Position FFC | FPC Connector Contacts | (0.50mm) Surface Mount | Right Angle |  |  | 1.1mm |  | Hirose | FH34SRJ-24S-0.5SH(99) |  |  | 798-FH34SRJ24S05SH99 | https://www.mouser.co.uk/ProductDetail/Hirose-Connector/FH34SRJ-24S-0.5SH99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
1 | MAX17048G+T10 | MAX17048G+T10 | SON50P200X200X80-9N | U4 | Check availability |  |  | In Stock |  | https://www.snapeda.com/parts/MAX17048G+T10/Analog+Devices/view-part/?ref=eda |  |  | 3µA 1-Cell/2-Cell Fuel Gauge with ModelGauge |  |  |  |  |  |  | Analog Devices |  |  |  |  |  | MAX17048G+T10 |  | TDFN-8 Maxim |  |  | None |  | https://www.snapeda.com/api/url_track_click_mouser/?unipart_id=329239&manufacturer=Analog Devices&part_name=MAX17048G+T10&search_term=None |  | https://www.snapeda.com/parts/MAX17048G+T10/Analog+Devices/view-part/?ref=snap
3 | MBR0530 | MBR0530 | SOD3716X135N | D3, D4, D5 | ON SEMICONDUCTOR - MBR0530 - DIODE, SCHOTTKY, 0.5A, 30V, SOD-123 |  |  | In Stock |  | https://www.snapeda.com/parts/MBR0530/Onsemi/view-part/?ref=eda |  |  | Diode Schottky 30 V 500mA Surface Mount SOD-123 |  |  |  |  |  |  | ON Semiconductor |  |  |  |  |  | MBR0530 |  | SOD-123-2 ON Semiconductor |  |  | None |  | https://www.snapeda.com/api/url_track_click_mouser/?unipart_id=179458&manufacturer=ON Semiconductor&part_name=MBR0530&search_term=None |  | https://www.snapeda.com/parts/MBR0530/Onsemi/view-part/?ref=snap
6 | PGB1010603MR | PGB1010603MR | DIOC1608X36N | D6, D8, D9, D10, D11, D12 | Check availability |  |  | In Stock |  | https://www.snapeda.com/parts/PGB1010603MR/Littelfuse/view-part/?ref=eda |  |  | 150V (Typ) Clamp - Ipp Tvs Diode Surface Mount 0603 (1608 Metric) |  |  |  |  |  |  | Littelfuse Inc. |  |  |  |  |  | PGB1010603MR |  | 0603 Littelfuse Inc. |  |  | None |  | https://www.snapeda.com/api/url_track_click_mouser/?unipart_id=5659453&manufacturer=Littelfuse Inc.&part_name=PGB1010603MR&search_term=None |  | https://www.snapeda.com/parts/PGB1010603MR/Littelfuse/view-part/?ref=snap
1 | QWIIC_RIGHT_ANGLE | QWIIC_CONNECTORJS-1MM | JST04_1MM_RA | J3 | SparkFun I2C Standard Qwiic Connector |  |  |  |  |  |  |  |  |  |  |  |  |  |  |  |  |  |  |  |  |  |  |  |  |  |  | CONN-13694 |  |  |  |  |  |  |  |  | QWIIC_RIGHT_ANGLE
1 | SAMACSYS_PARTS_USB4110-GF-A | SAMACSYS_PARTS_USB4110-GF-A | SAMACSYS_PARTS_USB4110GFA | J2 | CONN USB 2.0 TYPE-C R/A SMT |  |  |  |  |  |  |  | CONN USB 2.0 TYPE-C R/A SMT |  |  | 3.26mm |  | GCT (GLOBAL CONNECTOR TECHNOLOGY) | USB4110-GF-A |  |  | 640-USB4110-GF-A | https://www.mouser.co.uk/ProductDetail/GCT/USB4110-GF-A?qs=KUoIvG%2F9IlYiZvIXQjyJeA%3D%3D
1 | SI1308EDL-T1-GE3 | SI1308EDL-T1-GE3 | SOT65P210X110-3N | Q3 | MOSFET N-Ch 30V 1.5A TrenchFET SC70 Vishay Si1308EDL-T1-GE3 N-channel MOSFET Transistor, 1.5 A, 30 V, 3-Pin SC-70 |  |  | In Stock |  | https://www.snapeda.com/parts/SI1308EDL-T1-GE3/Vishay+Siliconix/view-part/?ref=eda |  |  | Si1308EDL-T1-GE3 N-channel MOSFET Transistor | 1.5 A | 30 V | 3-Pin SC-70 | Siliconix / Vishay SI1308EDL-T1-GE3 |  |  |  |  |  |  | Vishay Siliconix |  |  |  |  |  | SI1308EDL-T1-GE3 |  | SOT-323 Vishay Semiconductor |  |  | None |  | https://www.snapeda.com/api/url_track_click_mouser/?unipart_id=274603&manufacturer=Vishay Siliconix&part_name=SI1308EDL-T1-GE3&search_term=None |  | https://www.snapeda.com/parts/SI1308EDL-T1-GE3/Vishay+Siliconix/view-part/?ref=snap
17 | TPTP20R | TPTP20R | TP20R | TP1, TP2, TP3, TP4, TP5, TP6, TP7, TP8, TP9, TP10, TP11, TP12, TP13, TP14, TP15, TP16, TP17 | Test pad |  |  |  |  |  |  |  |  |  |  |  |  |  |  |  |  |  |  |  |  |  |  |  | 2
1 | USBLC6-2SC6Y | USBLC6-2SC6Y | SOT95P280X145-6N | D1 | Low Cap. ESD Protection Auto SOT-23-6 STMicroelectronics USBLC6-2SC6Y, Dual Uni-Directional TVS Diode Array, 6-Pin SOT-23 |  |  | In Stock |  | https://www.snapeda.com/parts/USBLC6-2SC6Y/STMicroelectronics/view-part/?ref=eda |  |  | 17V Clamp 5A (8/20µs) Ipp Tvs Diode Surface Mount SOT-23-6 |  |  |  |  |  |  | STMicroelectronics |  |  |  |  |  | USBLC6-2SC6Y |  | SOT-23-6 STMicroelectronics |  |  | None |  |  |  | https://www.snapeda.com/parts/USBLC6-2SC6Y/STMicroelectronics/view-part/?ref=snap
1 | W25Q512JVEIQ | W25Q512JVEIQ | SON127P600X800X80-9N | U1 | Check availability |  |  | In Stock |  | https://www.snapeda.com/parts/W25Q512JVEIQ/Winbond+Electronics/view-part/?ref=eda |  |  | FLASH - NOR Memory IC 512Mb (64M x 8) SPI - Quad I/O 133 MHz 8-WSON (8x6) |  |  |  |  |  |  | Winbond Electronics |  |  |  |  |  | W25Q512JVEIQ |  | Package |  |  | None |  |  |  | https://www.snapeda.com/parts/W25Q512JVEIQ/Winbond+Electronics/view-part/?ref=snap
1 | XC6220A331MR-G | XC6220A331MR-G | SOT95P280X120-5N | IC4 | LDO Voltage Regulators |  |  |  |  |  |  |  | LDO Voltage Regulators |  |  | 1.2mm |  | Torex | XC6220A331MR-G |  |  | 865-XC6220A331MR-G | https://www.mouser.co.uk/ProductDetail/Torex-Semiconductor/XC6220A331MR-G?qs=AsjdqWjXhJ8ZSWznL1J0gg%3D%3D

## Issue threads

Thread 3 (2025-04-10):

Update 3D PCB

gabruellita, 2025-04-10:
După rezolvarea problemei cu vizibilitatea via-stitching-ului în 2D (issue anterior), este necesar să reîncarc atât PCB-ul 3D, cât și modelul complet cu toate piesele în carcasă, pentru a reflecta cea mai recentă versiune a PCB-ului.

Closed 2025-04-13.

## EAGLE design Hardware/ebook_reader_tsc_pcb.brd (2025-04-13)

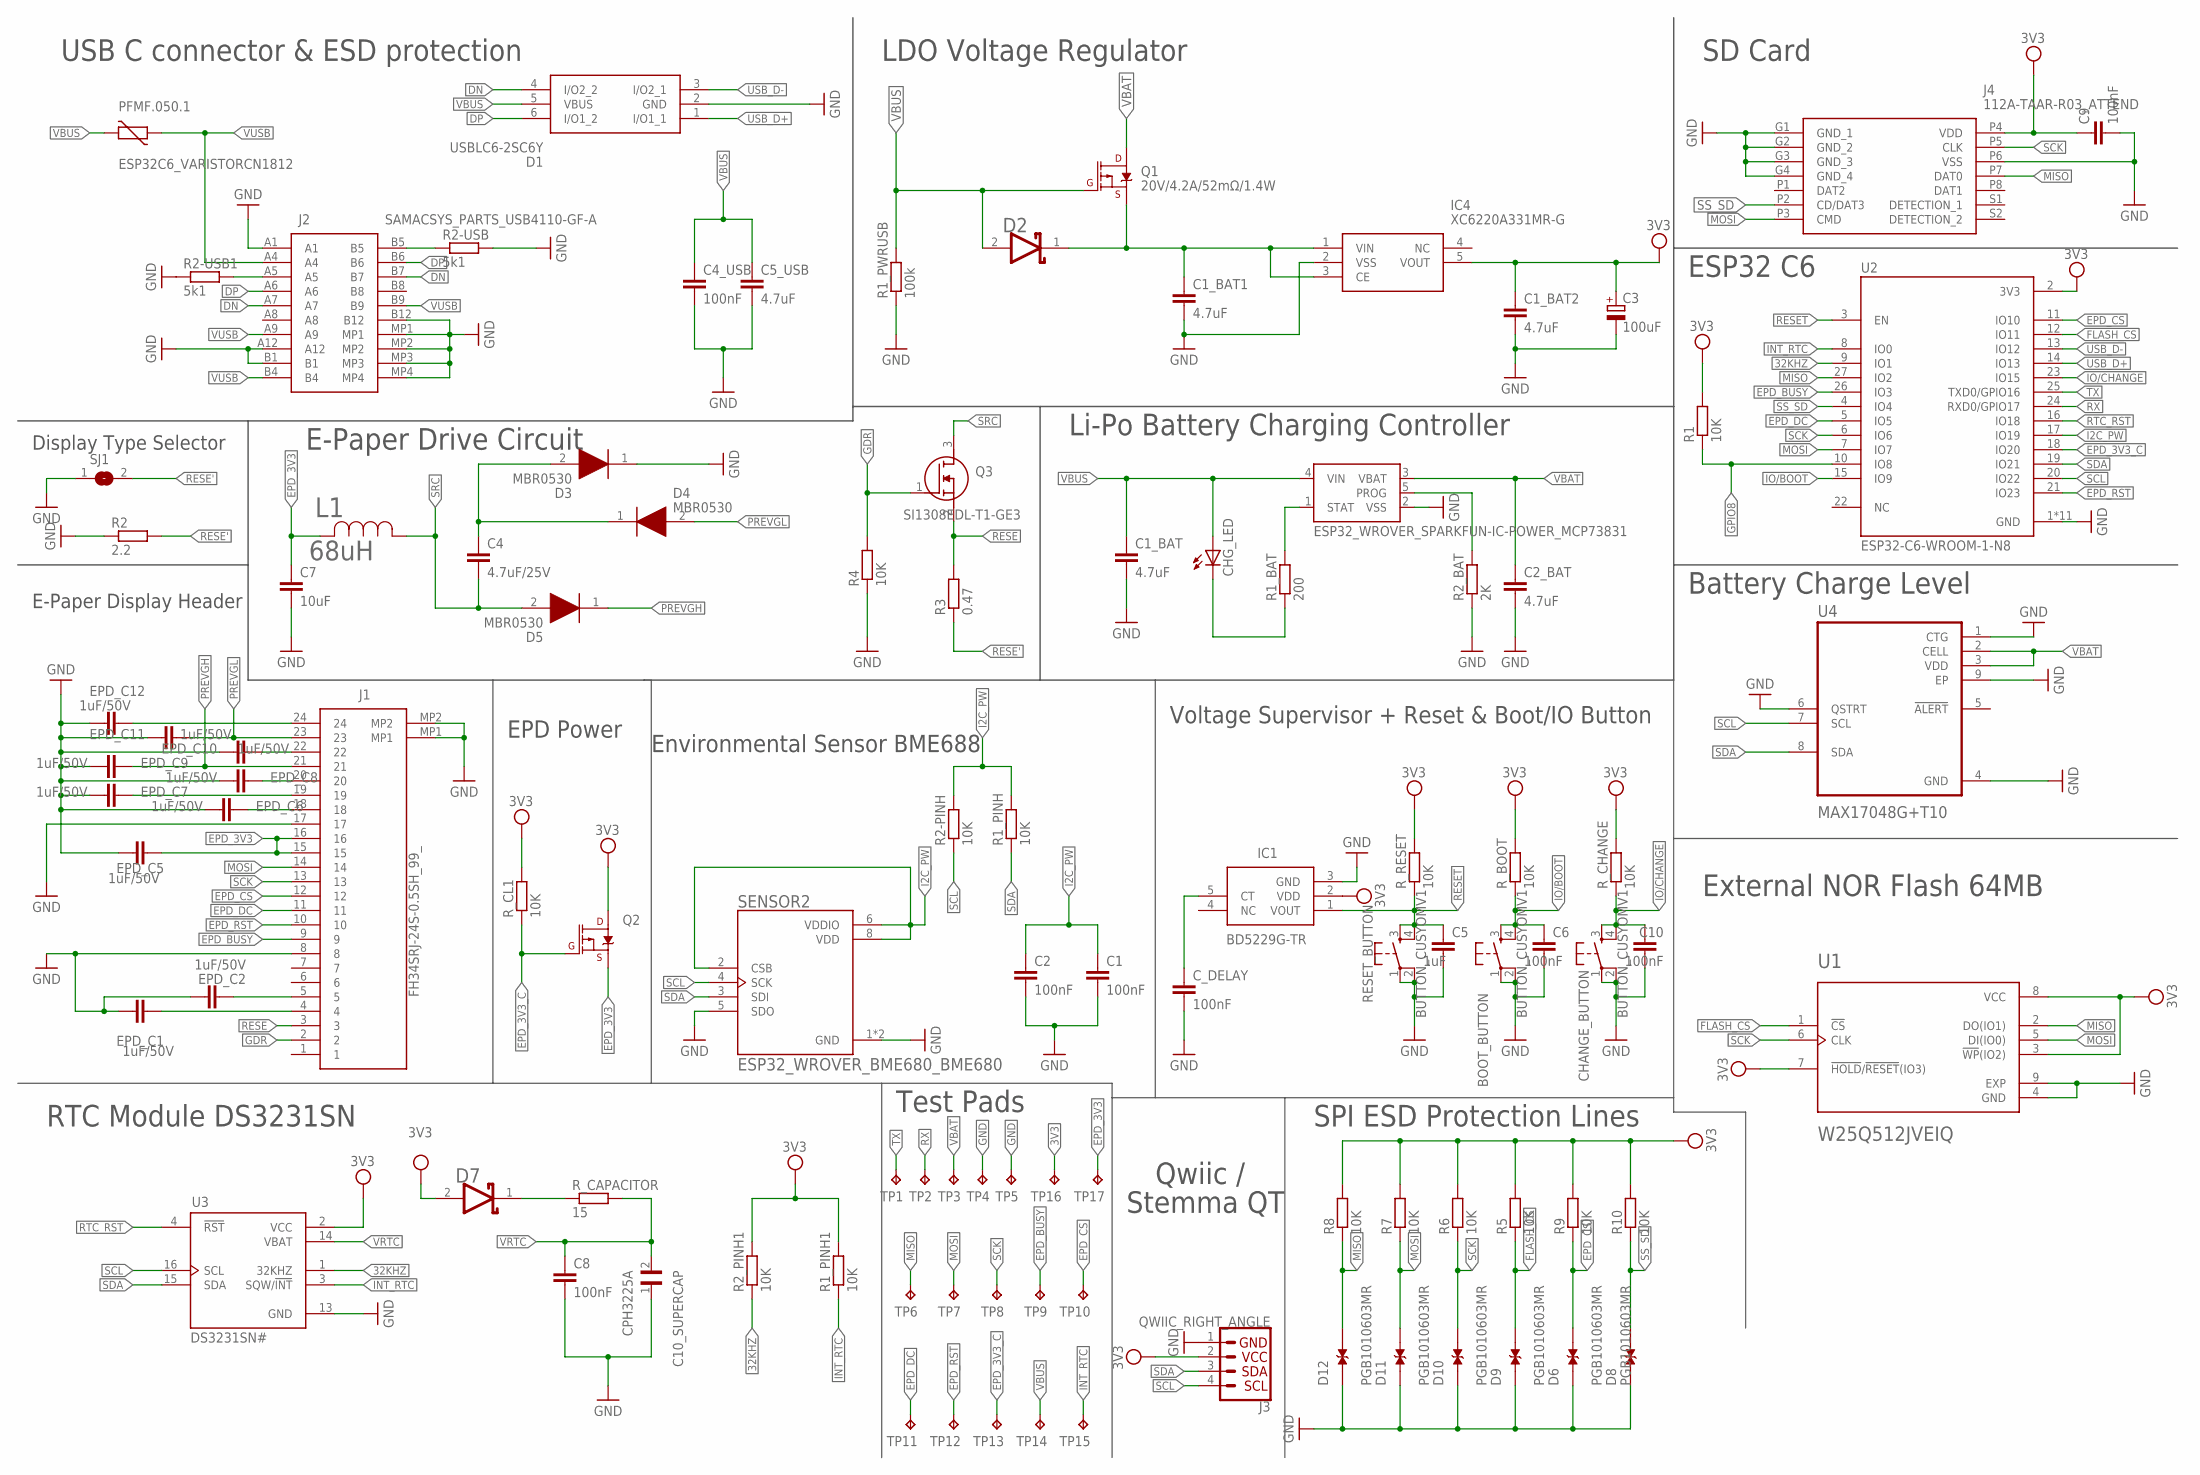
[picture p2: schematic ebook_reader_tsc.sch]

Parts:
BOOT_BUTTON: BUTTON_CUSYOMV1; MYBUTTON
C1, C2, C4_USB, C6, C8, C9, C10: 100nF; ESP32_WROVER_EAGLE-LTSPICE_C0402
C1_BAT, C1_BAT1, C1_BAT2, C2_BAT, C5_USB: 4.7uF; ESP32_WROVER_EAGLE-LTSPICE_C0402
C3: 100uF; RCL_CT3528
C4: 4.7uF/25V; ESP32_WROVER_EAGLE-LTSPICE_C0402
C5: 1uF; ESP32_WROVER_EAGLE-LTSPICE_C0402
C7: 10uF; ESP32_WROVER_EAGLE-LTSPICE_C0402
C10_SUPERCAP: CPH3225A; CAPCP3225X100N
CHANGE_BUTTON: BUTTON_CUSYOMV1; MYBUTTON
CHG_LED: ADAFRUIT_LEDCHIP-LED0603; ADAFRUIT_CHIP-LED0603
C_DELAY: 100nF; ESP32_WROVER_EAGLE-LTSPICE_C0402
D1: USBLC6-2SC6Y; SOT95P280X145-6N
D2, D7: ESP32_WROVER_AVX---SD0805S020S1R0_AVX_SD0805S020S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; ESP32_WROVER_AVX---SD0805S020S1R0_AVX_SD0805S020S1R0_0
D3, D4, D5: MBR0530; SOD3716X135N
D6, D8, D9, D10, D11, D12: PGB1010603MR; DIOC1608X36N
EPD_C1, EPD_C2, EPD_C5, EPD_C6, EPD_C7, EPD_C8, EPD_C9, EPD_C10, EPD_C11, EPD_C12: 1uF/50V; ESP32_WROVER_EAGLE-LTSPICE_C0402
IC1: BD5229G-TR; SOT95P280X125-5N
IC4: XC6220A331MR-G; SOT95P280X120-5N
J1: FH34SRJ-24S-0.5SH_99_; FH34SRJ24S05SH99
J2: SAMACSYS_PARTS_USB4110-GF-A; SAMACSYS_PARTS_USB4110GFA
J3: QWIIC_RIGHT_ANGLE; JST04_1MM_RA
J4: 112A-TAAR-R03_ATTEND; 112ATAARR03ATTEND
L1: 68uH; IND_4828-WE-TPC_WRE
MCP73831: ESP32_WROVER_SPARKFUN-IC-POWER_MCP73831; ESP32_WROVER_SPARKFUN-IC-POWER_SOT23-5
PFMF.050.1: ESP32C6_VARISTORCN1812; ESP32C6_VARISTOR_CT/CN1812
Q1, Q2: 20V/4.2A/52mΩ/1.4W; ESP32_WROVER_SPARKFUN-DISCRETESEMI_SOT23-3
Q3: SI1308EDL-T1-GE3; SOT65P210X110-3N
R1, R1_PINH, R1_PINH1, R2-PINH, R2_PINH1, R4, R5, R6, R7, R8, R9, R10: 10K; ESP32_WROVER_EAGLE-LTSPICE_R0402
R1_BAT: 200; ESP32_WROVER_EAGLE-LTSPICE_R0402
R1_PWRUSB: 100k; ESP32_WROVER_EAGLE-LTSPICE_R0402
R2: 2.2; ESP32_WROVER_EAGLE-LTSPICE_R0402
R2-USB, R2-USB1: 5k1; ESP32_WROVER_EAGLE-LTSPICE_R0402
R2_BAT: 2K; ESP32_WROVER_EAGLE-LTSPICE_R0402
R3: 0.47; ESP32_WROVER_EAGLE-LTSPICE_R0402
RESET_BUTTON: BUTTON_CUSYOMV1; MYBUTTON
R_BOOT: 10K; ESP32_WROVER_EAGLE-LTSPICE_R0402
R_CAPACITOR: 15; ESP32_WROVER_EAGLE-LTSPICE_R0402
R_CHANGE: 10K; ESP32_WROVER_EAGLE-LTSPICE_R0402
R_CL1: 10K; ESP32_WROVER_EAGLE-LTSPICE_R0402
R_RESET: 10K; ESP32_WROVER_EAGLE-LTSPICE_R0402
SENSOR2: ESP32_WROVER_BME680_BME680; ESP32_WROVER_BME680_PSON80P300X300X100-8N
SJ1: SJ
TP1, TP2, TP3, TP4, TP5, TP6, TP7, TP8, TP9, TP10, TP11, TP12, TP13, TP14, TP15, TP16, TP17: TPTP20R; TP20R
U1: W25Q512JVEIQ; SON127P600X800X80-9N
U2: ESP32-C6-WROOM-1-N8; XCVR_ESP32-C6-WROOM-1-N8
U3: DS3231SN#; SOIC127P1032X265-16N
U4: MAX17048G+T10; SON50P200X200X80-9N

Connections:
3V3: C1_BAT2.1, C3.+, C9.1, D7.2 (ANODE), IC1.2 (VDD), IC4.5 (VOUT), J3.2, J4.P4 (VDD), Q2.3 (D), R1.2, R1_PINH1.2, R2_PINH1.2, R5.2, R6.2, R7.2, R8.2, R9.2, R10.2, R_BOOT.2, R_CHANGE.2, R_CL1.2, R_RESET.2, TP16.TP, U1.3 (!WP!(IO2)), U1.7 (!HOLD!/!RESET!(IO3)), U1.8 (VCC), U2.2 (3V3), U3.2 (VCC)
32KHZ: R2_PINH1.1, U2.9 (IO1), U3.1 (32KHZ)
DN: D1.4 (I/O2_2), J2.A7, J2.B7
DP: D1.6 (I/O1_2), J2.A6, J2.B6
EPD_3V3: C7.1, EPD_C5.2, J1.15, J1.16, L1.2, Q2.2 (S), TP17.TP
EPD_3V3_C: Q2.1 (G), R_CL1.1, TP13.TP, U2.18 (IO20)
EPD_BUSY: J1.9, TP9.TP, U2.26 (IO3)
EPD_CS: D6.2, J1.12, R9.1, TP10.TP, U2.11 (IO10)
EPD_DC: J1.11, TP11.TP, U2.5 (IO5)
EPD_RST: J1.10, TP12.TP, U2.21 (IO23)
FLASH_CS: D9.2, R5.1, U1.1 (!CS), U2.12 (IO11)
GDR: J1.2, Q3.1 (G), R4.2
GND: BOOT_BUTTON.1, BOOT_BUTTON.2, C1.2, C1_BAT.2, C1_BAT1.2, C1_BAT2.2, C2.2, C2_BAT.2, C3.-, C4_USB.2, C5.2, C5_USB.2, C6.2, C7.2, C8.2, C10.2, C10_SUPERCAP.1, CHANGE_BUTTON.1, CHANGE_BUTTON.2, C_DELAY.2, D1.2 (GND), D3.1 (K), D6.1, D8.1, D9.1, D10.1, D11.1, D12.1, EPD_C1.1, EPD_C2.1, EPD_C5.1, EPD_C6.1, EPD_C7.1, EPD_C8.1, EPD_C9.1, EPD_C10.1, EPD_C11.1, EPD_C12.1, IC1.3 (GND), IC4.2 (VSS), J1.8, J1.17, J1.MP1, J1.MP2, J2.A12, J2.B1, J2.B12, J2.MP1, J2.MP2, J2.MP3, J2.MP4, J3.1, J4.G1 (GND_1), J4.G2 (GND_2), J4.G3 (GND_3), J4.G4 (GND_4), MCP73831.2 (VSS), R1_PWRUSB.1, R2.1, R2-USB.2, R2-USB1.1, R2_BAT.1, R4.1, RESET_BUTTON.1, RESET_BUTTON.2, SENSOR2.1 (GND), SENSOR2.5 (SDO), SENSOR2.7 (GND), SJ1.1, TP4.TP, TP5.TP, U1.4 (GND), U1.9 (EXP), U2.1 (GND), U2.28 (GND), U2.29_1 (GND), U2.29_2 (GND), U2.29_3 (GND), U2.29_4 (GND), U2.29_5 (GND), U2.29_6 (GND), U2.29_7 (GND), U2.29_8 (GND), U2.29_9 (GND), U3.13 (GND), U4.1 (CTG), U4.4 (GND), U4.6 (QSTRT), U4.9 (EP)
GPIO8: R1.1, U2.10 (IO8)
I2C_PW: C1.1, C2.1, R1_PINH.2, R2-PINH.2, SENSOR2.2 (CSB), SENSOR2.6 (VDDIO), SENSOR2.8 (VDD), U2.17 (IO19)
INT_RTC: R1_PINH1.1, TP15.TP, U2.8 (IO0), U3.3 (SQW/!INT)
IO/BOOT: BOOT_BUTTON.3, BOOT_BUTTON.4, C6.1, R_BOOT.1, U2.15 (IO9)
IO/CHANGE: C10.1, CHANGE_BUTTON.3, CHANGE_BUTTON.4, R_CHANGE.1, U2.23 (IO15)
MISO: D12.2, J4.P7 (DAT0), R8.1, TP6.TP, U1.2 (DO(IO1)), U2.27 (IO2)
MOSI: D11.2, J1.14, J4.P3 (CMD), R7.1, TP7.TP, U1.5 (DI(IO0)), U2.7 (IO7)
unnamed: J2.A5, R2-USB1.2
unnamed: J2.B5, R2-USB.1
unnamed: MCP73831.5 (PROG), R2_BAT.2
unnamed: C1_BAT1.1, D2.1 (CATHODE), IC4.1 (VIN), IC4.3 (CE), Q1.2 (S)
unnamed: C9.2, J4.P6 (VSS)
unnamed: CHG_LED.C, R1_BAT.1
unnamed: C4.1, D3.2 (A), D4.1 (K)
unnamed: MCP73831.1 (STAT), R1_BAT.2
unnamed: EPD_C1.2, J1.4
unnamed: C_DELAY.1, IC1.5 (CT)
unnamed: D7.1 (CATHODE), R_CAPACITOR.1
unnamed: EPD_C2.2, J1.5
unnamed: EPD_C12.2, J1.24
unnamed: EPD_C10.2, J1.22
unnamed: EPD_C8.2, J1.20
unnamed: EPD_C7.2, J1.19
unnamed: EPD_C6.2, J1.18
PREVGH: D5.1 (K), EPD_C9.2, J1.21
PREVGL: D4.2 (A), EPD_C11.2, J1.23
RESE: J1.3, Q3.2 (S), R3.2
RESE': R2.2, R3.1, SJ1.2
RESET: C5.1, IC1.1 (VOUT), RESET_BUTTON.3, RESET_BUTTON.4, R_RESET.1, U2.3 (EN)
RTC_RST: U2.16 (IO18), U3.4 (!RST)
RX: TP2.TP, U2.24 (RXD0/GPIO17)
SCK: D10.2, J1.13, J4.P5 (CLK), R6.1, TP8.TP, U1.6 (CLK), U2.6 (IO6)
SCL: J3.4, R2-PINH.1, SENSOR2.4 (SCK), U2.20 (IO22), U3.16 (SCL), U4.7 (SCL)
SDA: J3.3, R1_PINH.1, SENSOR2.3 (SDI), U2.19 (IO21), U3.15 (SDA), U4.8 (SDA)
SRC: C4.2, D5.2 (A), L1.1, Q3.3 (D)
SS_SD: D8.2, J4.P2 (CD/DAT3), R10.1, U2.4 (IO4)
TX: TP1.TP, U2.25 (TXD0/GPIO16)
USB_D+: D1.1 (I/O1_1), U2.14 (IO13)
USB_D-: D1.3 (I/O2_1), U2.13 (IO12)
VBAT: C2_BAT.1, MCP73831.3 (VBAT), Q1.3 (D), TP3.TP, U4.2 (CELL), U4.3 (VDD)
VBUS: C1_BAT.1, C4_USB.1, C5_USB.1, CHG_LED.A, D1.5 (VBUS), D2.2 (ANODE), MCP73831.4 (VIN), PFMF.050.1.2, Q1.1 (G), R1_PWRUSB.2, TP14.TP
VRTC: C8.1, C10_SUPERCAP.2, R_CAPACITOR.2, U3.14 (VBAT)
VUSB: J2.A4, J2.A9, J2.B4, J2.B9, PFMF.050.1.1

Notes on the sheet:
USB C connector & ESD protection
LDO Voltage Regulator
SD Card
ESP32 C6
Display Type Selector
Li-Po Battery Charging Controller
E-Paper Drive Circuit
Battery Charge Level
External NOR Flash 64MB
SPI ESD Protection Lines
Voltage Supervisor + Reset & Boot/IO Button
Qwiic /
Stemma QT
Test Pads
RTC Module DS3231SN
Environmental Sensor BME688
EPD Power
E-Paper Display Header

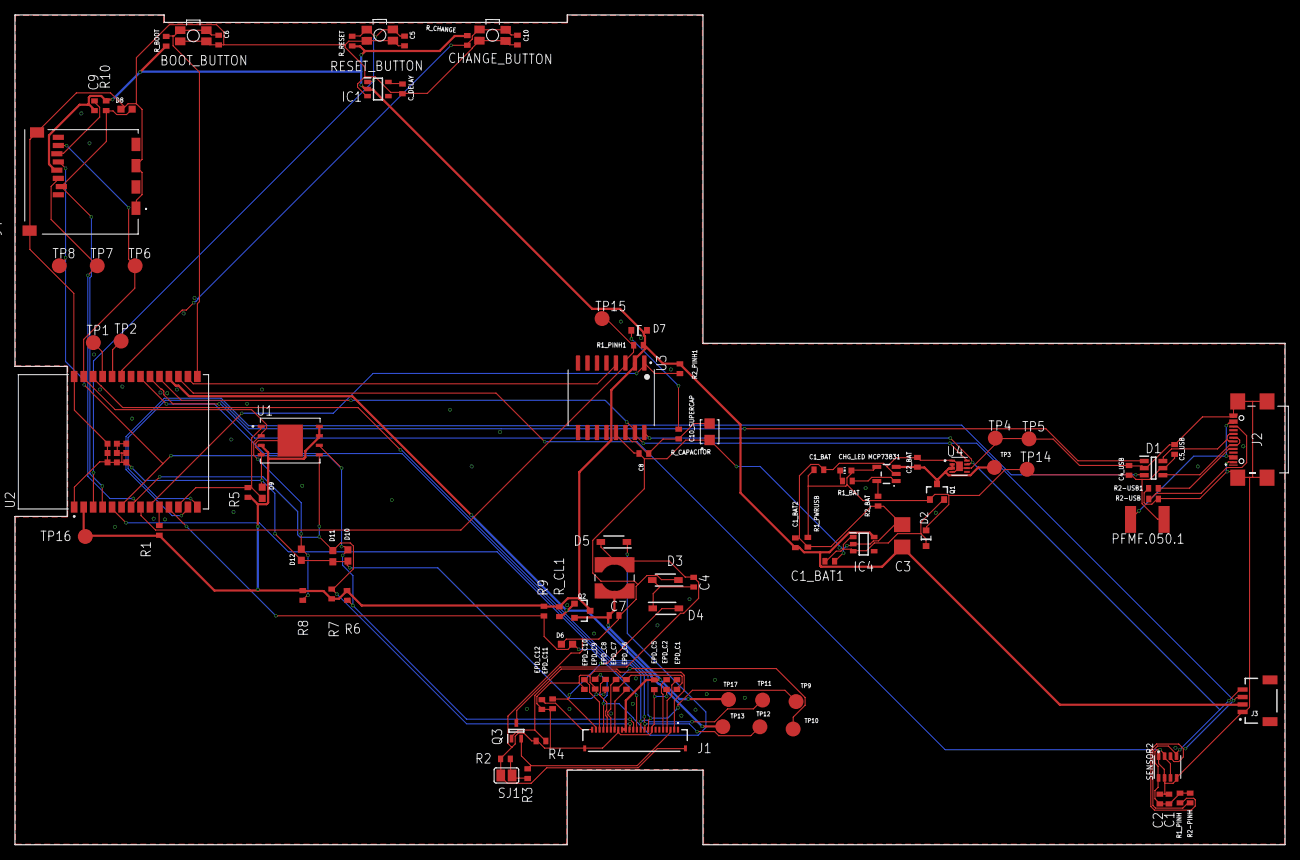
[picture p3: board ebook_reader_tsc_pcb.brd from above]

Board: 2 copper layers, 170.2 x 111.2 mm, 103 parts (0 on the bottom side), 56 nets.

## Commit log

2025-04-13 updated pcb
    solved via stitching and overlapping layer names
    [ebook_reader_tsc_pcb.brd]
2025-04-13 updated 3d
    3d pcb after modifying 2d pcb

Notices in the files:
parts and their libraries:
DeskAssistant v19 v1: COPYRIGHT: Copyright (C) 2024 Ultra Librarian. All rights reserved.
